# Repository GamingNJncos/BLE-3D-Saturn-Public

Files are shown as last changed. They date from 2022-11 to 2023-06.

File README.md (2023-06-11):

# BLE-3D #
Sega Saturn 3D Controller Bluetooth(BLE) Adapter

# **What does it do?** #
- This is an open source and completely solderless adapter for the Sega Saturn 3D Controller that converts it to a Bluetooth(BLE) HID Gamepad. 
- The end result demonstrates a battery powered and solderless adapter that allows you to use one of the best controllers ever made to date across numerous consoles

### Highlights ###
- **Zero modifications to the factory controller** are neccesary to build, test, or play with this adapter.
- Both Analog, and Digital mode (switch on controller) are fully supported
- Want to revert back to OE? Simply plug the OE cable back in. 
- Latency testing pin on-pcb offers consistent and reproducible testing across code changes and development

### Lowlights ###
- This isn't a "retail ready product", it's a proof of concept
- No case for this has been published yet (bare pcb)
- Power circuit has a couple issues. More details in Caveats section

# **Compatibility** #
 This is an area I'm extremely proud of as of writing the BLE3D is known to work with: 
  - Windows, Linux, and Steamdeck
  - ALL supported [Blueretro](https://github.com/darthcloud/BlueRetro) consoles 
  - That means the 3D is now available on (in no particular order)
        - NeoGeo, Supergun, JAMMA
	- Atari 2600/7800, Master System
	- NES, PCE / TG16, Mega Drive / Genesis, SNES
	- CD-i, 3DO, Jaguar, Saturn, PSX, PC-FX, 
	- JVS (Arcade), Virtual Boy, N64, Dreamcast, PS2, GameCube & Wii
	- I'm sure I'm missing a handful
 
  - Note: the analog pad/triggers support are per console, there is no 'digital emulation' on the analog stick.

# **Background** #
For years I've dreamed of a wireless Sega Saturn 3d Pad, just like the patents intended.

- [US Patent Number US 7488,254 B2](https://patentimages.storage.googleapis.com/a2/97/47/e77a8c63165461/US7488254.pdf)
- [US Patent Number Des. 409, 149](https://patentimages.storage.googleapis.com/3d/96/ad/edd675699738cf/USD409149.pdf)
- [European Patent Number EP 1 332 778 B1](https://patentimages.storage.googleapis.com/ed/ba/17/c22422d5d3cc47/EP1332778B1.pdf)
An inspiration image I have been using in development 

Fast forward many years, I stumbled across some work [Hexfreq](https://twitter.com/hexfreq) was doing with arduino and asked if I could take a look at the code. The rest is history.
From there [Humble Bazooka](https://twitter.com/humblebazooka) and I have spent countless hours to make sure this was a reality. I'd be remissed to leave out [darthcloud](https://twitter.com/darthcloud64) has also been an immense help along the way.

# **PCBs** #
- There are 2 publicly available DIY pcb's for "dev kits". 
- There are various issues or design misses with both pcbs
- They aren't intended for retail use, but you can build one yourself **today**.
- Beveling the controller facing pins is advised 

## **LightWing** ##
 - This is a 'new' revision of the BLE-Saturn-3D that focuses on core functionality. This was optimized as the low cost option for home builders. At current, this is the advised version to use until development can progress farther on the extra features of the HeavyWing 
- PCB: https://oshpark.com/shared_projects/7RqwDWJT 
<BR>  <BR>

## **HeavyWing** ##
- The original PCB. Take the above patents put them in a blender. It adds LCD Support, Motion Controls & Rumble. You can use the LightWing code (better performance) on a Heavywing PCB but will need to change some pin mappings.
- PCB: https://oshpark.com/shared_projects/ki7HbZV4
<BR>  <BR><BR> 

# **BOM** #
## LightWing ###
 - 1x [LightWing PCB](https://oshpark.com/shared_projects/7RqwDWJT)
 - 1x [Adafruit Feather Huzzah32](https://www.adafruit.com/product/3405)
 - 1x Battery
<BR><BR> 
	
## HeavyWing ##
 - 1x [HeavyWing PCB](https://oshpark.com/shared_projects/ki7HbZV4)
 - 1x [Adafruit Feather Huzzah32](https://www.adafruit.com/product/3405) 
 - 1x [HiLetgo GY-521 AKA MPU-6050 Tilt Sensor](http://hiletgo.com/ProductDetail/2157948.html)*  (optional - while it does "work" the kalman filter needs some rework. Must support 3.3v, some are 5v only) 
- 1x OLED 128X64 SSD1306 (optional)
- 1x 3.3v Rumble Motor* (optional - this circuit is not populated on the PCB currently)
- 1x Battery
<BR><BR> 

# **Assembly** #
- Assembly is straightforward, it's just a PCB sandwhich and some solder
- Orientation might be counter intuitive

 ### **LightWing - Assembly** ###
- When you build this lay Segata Face-Down, then set the Feather through the holes with the ESP, USB, and Battery plug facing you
- This provies some additional space for the battery directly under the PCB which would closet match the original patent docs visually
<BR>  <BR>

 ### **LightWing - Installation** ###
- Sega Logo and Button Face top
- Segata faces triggers or back of controller
<BR>   <BR>  <BR>

  ### **HeavyWing - Assembly** ###
   - *Pictures to be uploaded soon*
  
<BR><BR>  
# **Before you compile the code** #
- [PlatformIO installed in VScode](https://docs.platformio.org/en/stable/tutorials/espressif32/arduino_debugging_unit_testing.html), the [platformio.ini](https://github.com/GamingNJncos/BLE-3D-Saturn-Public/blob/main/platformio.ini), and the main.cpp for the Lightwing or the Heavywing
- This has not been tested with Arduino IDE extensively but should compile fine however extremely slow
- If you are mixing and matching LightWing code with the HeavyWing PCB, make sure you change the pinmapping. 
- This is well documented in the code if you jump to "Pinmappings for your PCB version"

## Powering the Device ##
This is direct from the [Adafruit Documentation](https://learn.adafruit.com/adafruit-huzzah32-esp32-feather/power-management)
- There's two ways to power a Feather:
- **You can connect with a USB cable** (just plug into the jack) and the Feather will regulate the 5V USB down to 3.3V.
-  **You can also connect a 4.2/3.7V Lithium Polymer** (LiPo/LiPoly) or Lithium Ion (LiIon) battery to the JST jack. This will let the Feather run on a rechargeable battery.
-  **When the USB power is powered, it will automatically switch over to USB for power**, as well as start charging the battery (if attached). 
- **This happens 'hot-swap' style** so you can always keep the LiPoly connected as a 'backup' power that will only get used when USB power is lost.

<BR><BR> 
# **Caveats and Gotchas** #
 ## A Note on the Huzzah32 revisions ##
  - Check your WROOM version before flashing!
  - There is a NEW revision of the huzzah32 shipping with the Wroom-32-**E** that will have some problems initially when plugged into the controller
  - This is a result of changes to pin IO12 between the D and E modules (and a bootstrap pin) 
  - PCB's were made based on result on the Wroom-32-**D** module and have no issues "out of the box"
  
  - On Wroom-E when the pcb is plugged into the controller at boot similar to boot:0x33 (SPI_FAST_FLASH_BOOT) **invalid header: 0xffffffff**
  - You can burn an efuse to work around this with the espefuse tool. Note this is irreversible, if you are uncomfortable with this try to find another vendor with the 32D in stock   - How to burn the efuse: `espefuse.py --port [com port] --baud 115200 set_flash_voltage 3.3V` confirm the fuse status with `espefuse -p [com port] --baud 115200 summary`. At the bottom it will say **Flash voltage (VDD_SDIO) set to 3.3V by efuse.**
- At the bottom it will say **Flash voltage (VDD_SDIO) set to 3.3V by efuse.**

 ## Battery Warning ##
  - It is *extremely* important that you check the polarity on your battery jack is oriented correctly. There is 0 polarity protection. The charging circuit WILL fry if you plug it in and it's backwards.

 ## Powering Down ##
  - Due to the design of the adafruit feather (esp32) there is no formal power switch. 
  - You must either solder a physical switch on to the battery, **or** unplug it. This is not always easy with the JST connector used so be careful.
 
  ## Charging ##
   - Another unfortunate aspect of the power circuit design on the feather is that the device must be powered on to charge. 
   - There is no "charging mode" so anytime the controller needs to charge it will be broadcasting. 
   - Deep sleep is the best solution for this long term but there are reassons it's not included just yet.

  ## Missing Trigger ##
   - In windows if you go to look at the button inputs in joy.cpl the right trigger is not displayed.  
   - The trigger is there, but you have to use another pad tester to "see it".
  - The picture below *is the expected behavior* and appears to be a problem with joy.cpl in particular.
	<BR> <BR> <BR>

## Various Demos and feature teasers ##
- [Taking Nights for a spin over Bluetooth](https://twitter.com/GamingNJncos/status/1537364206881755136)
- [LCD and customizable Boot Logo](https://twitter.com/GamingNJncos/status/1532819934551724033)
- [Pad Test Demo in X-Men COTA](https://twitter.com/GamingNJncos/status/1537362477817765889)
- [Steamdek Test](https://twitter.com/GamingNJncos/status/1540845741710745602)
- [Early External Unit Testing](https://twitter.com/GamingNJncos/status/1404144038693986307)

## Latency Testing ##
- A significant amount of consideration went into making it easy to test code changes and the impact on latency
- The Lightwing PCB has a dedicated solder pad for consistent testing methodology and code incorporates easy to toggle enable/disable for the pin
- Documentation on the process is available [here](https://github.com/GamingNJncos/BLE-3D-Saturn-Public/tree/main/BlueRetro_Latency_Testing)

## **Note on the Boot Logos (Supported on HeavyWing PCB)** ##
This is documented in the code however if you want to convert images [this tool](https://lcd-image-converter.riuson.com/en/about/) is really useful  
<BR>  <BR>

## Whats with the Names? ##
- Feather add-ons or expansions (hat equivalent for raspberry pi) are called "Wings". 
- Combine that with some Sega nerd-lore and you the [Heavy Wing](https://panzerdragoon.fandom.com/wiki/Heavy_Wing) and [Light Wing](https://panzerdragoon.fandom.com/wiki/Light_Wing)

<BR><BR>

# **Strange notes and pedantic details** #
 ## Protocol Details and Resources ##
 - [A great overview across numerous sega consoles](https://hackaday.io/project/170365-blueretro/log/180790-evolution-of-segas-io-interface-from-sg-1000-to-saturn) by [darthcloud](https://twitter.com/darthcloud64)
 - [Additional protocol details for the Saturn](http://forums.modretro.com/index.php?threads/saturn-controller-protocol-mk80116-mk80100.11328/)

 ## Saturn 3D supported Game list, patent details, and more ##
https://segaretro.org/3D_Control_Pad
 
 ## Polling Oddity or Opportunity? ## 
The [Saturn only polls the 3D protocol at 16ms intervals](https://nfggames.com/forum2/index.php?topic=5055.0) (screen blank). There is however some suggestion in the below post that the Action Replay (this is firmware version specific) can attempt polling faster.  It's worth taking a look at as it may be possible to force games into a faster mode with patching.

Qoute:
"For whatever reason, it's only polling the controller for 14.25ms, with around 310us pauses in between, so it's polling much quicker, but the real issue is after this 14.25ms is up, it then drives the SEL line Hi and goes about it's business for ~2.5ms after that, then back to polling."

## Other demos and informational links ##
- [A DIY internal BlueRetro receiver for Saturn](https://twitter.com/nosIndulgences/status/1573719805496299520)
- [Hexfreq showing off a completely differnt bluetooth saturn solution](https://twitter.com/hexfreq/status/1468282054978818062)

## **Libraries in use** ##
- [ESP32-BLE-Gamepad](https://github.com/lemmingDev/ESP32-BLE-Gamepad)
 - This is subject to change long term as new and improved libraries emerge to support BLE HID gamepads

- [NimBLE-Arduino](https://github.com/h2zero/NimBLE-Arduino)

## **Details on the Feather** ##
- If you want to remix the PCB's or understand more about the feather itself check out the following
- [Feather Pinouts and hardware overview](https://learn.adafruit.com/adafruit-huzzah32-esp32-feather/pinouts)

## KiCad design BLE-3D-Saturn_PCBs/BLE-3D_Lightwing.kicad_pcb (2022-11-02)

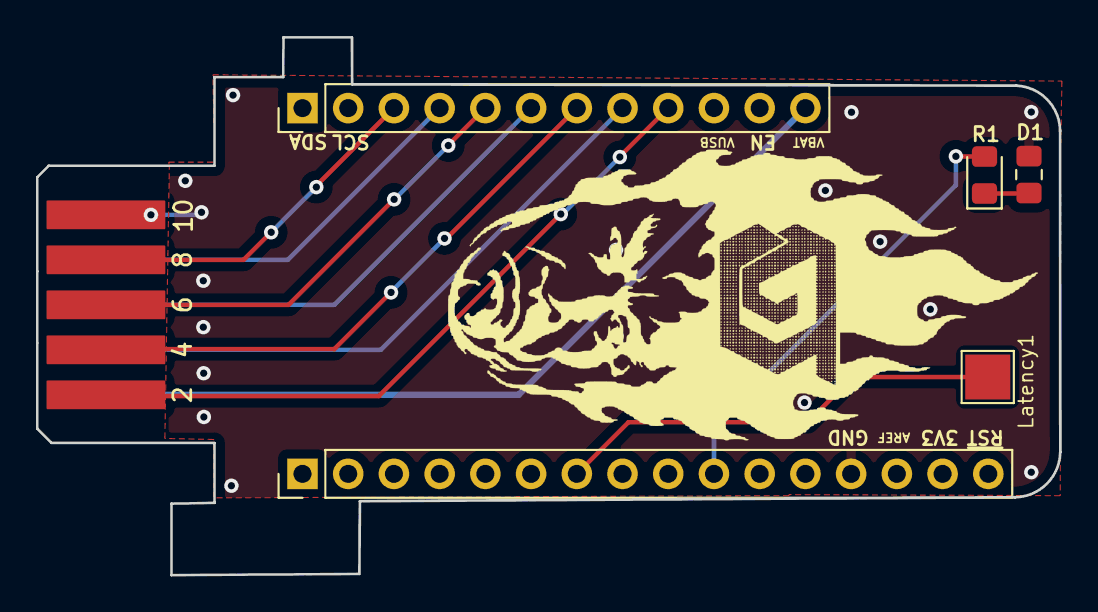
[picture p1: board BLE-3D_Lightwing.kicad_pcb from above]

Board: 2 copper layers, 56.8 x 29.9 mm, 6 parts (1 on the bottom side), 12 nets.

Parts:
D1: LED_Small; R_0805_2012Metric_Pad1.15x1.40mm_HandSolder
J1: feather long; PinHeader_1x16_P2.54mm_Vertical
J2: feather short; PinHeader_1x12_P2.54mm_Vertical
Latency1: Latency; TestPoint_Pad_2.5x2.5mm
R1: R_Small; LED_0805_2012Metric_Pad1.15x1.40mm_HandSolder
U1: Saturn_3D_Pinout; Saturn_Controller_Pinout_2

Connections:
BatLED: J1.10, R1.2
D0: J2.8, U1.3
D1: J2.9, U1.2
D2: J2.3, U1.8
D3: J2.4, U1.7
GND: D1.1, J1.13, U1.9, U1.10
Latency: J1.7, Latency1.1
unnamed: D1.2, R1.1
TH: J2.7, U1.4
TL: J2.5, U1.6
TR: J2.6, U1.5
VBAT: J2.12, U1.1

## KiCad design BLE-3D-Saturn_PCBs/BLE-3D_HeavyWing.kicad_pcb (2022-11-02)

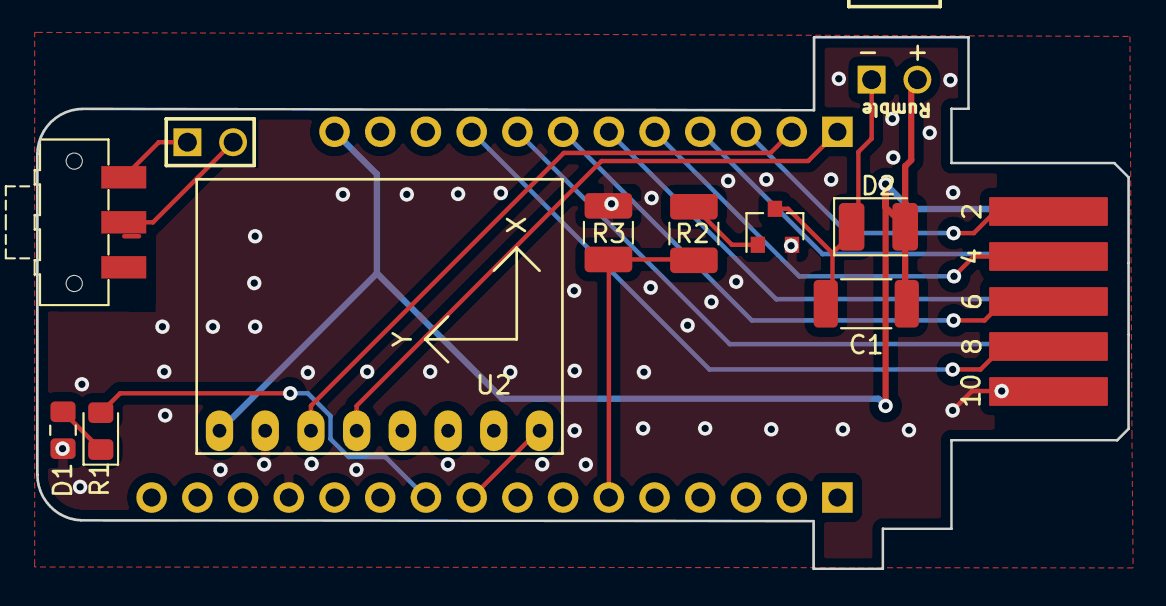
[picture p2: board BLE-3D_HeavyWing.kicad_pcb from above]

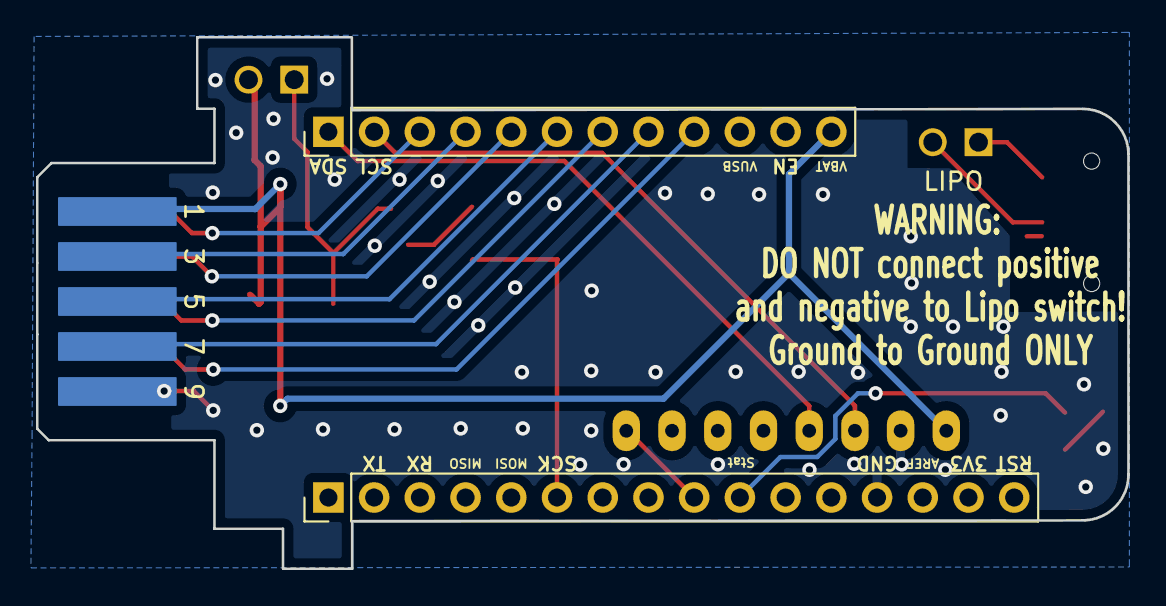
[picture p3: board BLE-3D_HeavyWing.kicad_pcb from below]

Board: 2 copper layers, 60.6 x 29.5 mm, 14 parts (3 on the bottom side), 18 nets.

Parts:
-  +: HEADER-FEMALE-2POS-TH-1x02-JST-PH; HEADER1x2HF
C1: C_Small; C_2010_5025Metric
D1: LED_Small; R_0805_2012Metric_Pad1.15x1.40mm_HandSolder
D2: DIODE; D_1210_3225Metric_Pad1.42x2.65mm_HandSolder
J1: feather long; PinHeader_1x16_P2.54mm_Vertical
J2: feather short; PinHeader_1x12_P2.54mm_Vertical
LIPO: HEADER1X2; HEADER1x2V
Q1: 2N7002; SOT-23
R1: R_Small; LED_0805_2012Metric_Pad1.15x1.40mm_HandSolder
R2, R3: R_Small; R_1210_3225Metric_Pad1.42x2.65mm_HandSolder
SW1: Power; SW_SPDT_CK-JS102011SAQN
U1: Saturn_3D_Pinout; Saturn_Controller_Pinout_2
U2: GY-521

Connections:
BAT_GND: LIPO.1, LIPO.2, SW1.1, SW1.2
BatLED: J1.10, R1.2
D0: J2.4, U1.3
D1: J2.3, U1.2
D2: J2.9, U1.8
D3: J2.8, U1.7
GND: D1.1, J1.13, Q1.2, R3.1, U1.9, U1.10, U2.2
INT: J1.9, U2.8
unnamed: - +.1, C1.2, D2.1, Q1.3
unnamed: D1.2, R1.1
unnamed: Q1.1, R2.2
SCL: J2.2, U2.3
SDA: J2.1, U2.4
TH: J2.5, U1.4
TL: J2.7, U1.6
TR: J2.6, U1.5
VBAT: - +.2, C1.1, D2.2, J2.12, U1.1, U2.1
VibeOut: J1.6, R2.1, R3.2

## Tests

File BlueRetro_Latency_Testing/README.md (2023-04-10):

# This is currently under construction.

# Forward (Rant)
If you are chasing low latency controllers and have never tested your display lag, you are approaching this *completely backwards*. If you are trying to blame controller latency before video as the culprit for how poorly you play games, reconsider. LAG is cumulative from input to output as far as your perception is concerned.

Some of the better projectors for example alone add 30-70ms of lag. It's not uncommon to see with a series of connected devices in path 40-60ms before hitting your "2ms" LCD. Even your LCD is unlikely to perform at advertised speeds outside of VERY specific configurations. Wrong setting, add 18+ms.  That's omitting any upscaler, AV Reciver in the middle, media converters, hdmi switches, etc - each of which may have setting based penalties. 

[RetroRGB](https://www.retrorgb.com/) has done extensive testing and how-to videos on the subject.

# Controller Latency Testing in General
Before we dive into the BLEGamepad/BlueRetro stuff, it's useful to understand how this testing is done in the wild elsewhere. Consistency is important across numerous controllers and setups. The best place to start is with the MiSTER. 

## What you need:
- [x] A controller      - This acts as the "Transmitter" for the keypress

- [x] Arduino Pro Micro - This performs time based calculation for Press->Recieve

- [x] Your reciver      - This is the "Receiving" device
 - For Mister this is via a custom USB Cable
 - It's BlueRetro for Bluetooth Controllers

## Detailed guide on how latency testing is performed on the Mister Platform:
https://www.cathoderayblog.com/lag-test-your-controller-mister-fpga-input-latency-tester/

I strongly advise taking a look over the content above as it will make everything from here much easier to understand. There are also a fair amount of videos floating around about this. Effectively you're using an arduino to "press" a button, and then another pin which will detect how fast that button is recieved on the other end.  The arduino acts as a timer to count the time from when the press is sent to the time it is received and starts the next loop. After *10,000+* itterations, you have a good average input latency.

## The BIG Mister Controller Latency List:
https://rpubs.com/misteraddons/inputlatency

This is a list of controller input latency tests providing a useful comparison across a wide array of controllers as to what is "low latency", whats "Normal" and what is unbearably slow. 

# Latency Testing with [BlueRetro](https://github.com/darthcloud/BlueRetro)
Darthcloud has included in BlueRetro a method to perform testing with the same arduino code that Mister uses. In brief you have to use the correct firmware, set the correct profile, and then use the right GPIO pin to connect to your arduino. You can read some more on this from his dev journal [here](https://hackaday.io/project/170365-blueretro/log/187443-2020-12-26-update-latency-tests-release-v010).

There are some caveats you should be aware of I have spent *many* hours beating my head on a desk over.

- [x] You **MUST** use the "parallel_1P_external.bin" when flashing firmware (Any firmware release version)
 - Console specific or embedded firmwares wont work
 - DO NOT connect your BR reciever to a console (Use **ONLY** external power)
	  
- [x] Before connecting your controller you **MUST** enable the "Latency Test" profile
 - If you fail to do this before connecting the controller you will have to power off the controller and reset blueretro or wait some time
 - Note: This often does not survive power down so confirm each time you need to power the BR adapter up again
	  
- [x] You **MUST** have access to GPIO26 on your BlueRetro testing device.  
 - This could be risky if you only have console BR specific versions that require modification for output pin and the external power (eg. Pre-built N64 Adapter)

- [x] You **MUST** have access to the PCB of your controller to solder on a wire for arduino to "press" your testing button
 - This typically requires modification to your controller PCB, like scraping away the coating to hit a copper trace.
 - This is also why my 3D Controller Lightwing PCBs have a dedicated pin on them to avoid damage.
 - Some controllers (including the Saturn 3D Pad) require a specific voltage (not just ground) so you may need to identify expected resistance

# Latency Testing with [ESP32-BLE-Gamepad](https://github.com/lemmingDev/ESP32-BLE-Gamepad)
ESP32-BLE-Gamepad does not contain any "specific" latency testing function. For testing you simply define a button that works when pulled low and to connect it to the correct controller facing arduino pin. In the code linked this pin should connect to arduino pin 5.
 -  A lesson learned here is to avoid sending a Button ID/Number used elsewhere in code as it will self cancel in your initial loop not being detected **OR** make sure your code contains a check for **all** places that should use the pin and send the update accordingly.

Defining a latency pin code example:
```
      if (digitalRead(latPin) == LOW) { //when arduino pulls this pin low send button press
        bleGamepad.press(BUTTON_1);
      } else {
        bleGamepad.release(BUTTON_1);
      }
```

# Latency test your ESP32-BLE-Gamepad controller with BlueRetro
 I have used "BR" in place of BlueRetro below

###  The Arduino Pro Micro
 1. Flash your Arduino with the [latency test code](https://github.com/misteraddons/inputlatency/blob/main/arduino/MiSTer_USB_Latency_Test_Lemonici/MiSTer_USB_Latency_Test_Lemonici.ino)

 2. Unplug your Arduino

###  The Controller
  3. Upload your ESP32-BLE-Gamepad code to your controller
 
  4. Turn the controller OFF

  5. Solder a wire to your controller pin to use for testing
 
  6. Connect the wire soldered to the controller to Arduino Pin 5
 
###  BlueRetro
  7. [Flash the "parallel_1P_external.bin"](https://github.com/darthcloud/BlueRetro/wiki/BlueRetro-DIY-Build-Instructions) to your BlueRetro reciever and power cycle it
 
  8. Connect GPIO26 (some boards may show as IO26) on BR to Pin 2 of the Arduino
 
  9. Using **Chrome Browser** [connect to BR over bluetooth](https://hackaday.io/project/170365-blueretro/log/180020-web-bluetooth-ble-configuration-interface) and set the mapping profile to "Latency Test" and click save 
 - Note:  There is a "Test" profile in the second box - do not use this.

 - Example of the correct setting:
the right way
     
 ### Start Latency Testing    
 10. Connect to the serial console of your arduino com port (115200 - 8 n 1) 
 - Failure to connect to serial will not allow the code to start running
     
 11. Power on your controller

 12. Check your Serial console to the arduino and confirm it is incrimenting. If so Allow 10k+ itterations to complete to get your latency data.
     Example of the blinking you should see when testing is working correctly.  Note, I you will only see 1 blink (on arduino) vs my install.
     Seizure Warning: the right way

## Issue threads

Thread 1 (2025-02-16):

collect2.exe: error: ld returned 1 exit status

PJSOConnell, 2025-02-16:
When uploading the LightWing main.cpp to the Adafruit Huzzah32, I get the following error.

collect2.exe: error: ld returned 1 exit status
*** [.pio\build\featheresp32\firmware.elf] Error 1

I have attached the full log.

[saturn_ble.txt](https://github.com/user-attachments/files/18816538/saturn_ble.txt)

Closed 2025-02-16.

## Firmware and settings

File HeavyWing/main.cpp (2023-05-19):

#include <Process.h>
#include <stdio.h>
// Add BLE Gamepad
#include <BleGamepad.h>  
// Add OLED
#include <Adafruit_GFX.h>
#include <Adafruit_SSD1306.h>
// Add Adafruit Sensor Libs for Tilt Controls
#include <Adafruit_Sensor.h>
#include <Adafruit_MPU6050.h>

//====================================================
// __________.____     ___________.________ _________   
// \______   \    |    \_   _____/ \_____  \\______  \  
//  |    |  _/    |     |    __)_    _(__  < |    |   \ 
//  |    |   \    |___  |        \  /       \|    `    \
//  |______  /_______ \/_______  / /______  /________  /
//         \/        \/        \/         \/         \/ 
// Greetz and massive thanks to Hexfreq for being a complete bad ass
//
// All reliable controller code foundation is from [at]Hexfreq
// All bugs, poor code choices, and existing PCB designs courtesy of [at]GamingNJncos
// Cheers to [at]Arthrimus for lighting this fire on accident
//
// As I have limited time for mainting this codebase long term attempts have been made to over document code provided
// No Warranty expressed or implied
//====================================================


// OLED Screen Settings
#define SCREEN_WIDTH 128 // OLED display width, in pixels
#define SCREEN_HEIGHT 64 // OLED display height, in pixels
#define OLED_RESET     4 // Reset pin # (or -1 if sharing Arduino reset pin)
#define SCREEN_ADDRESS 0x3C ///< See datasheet for Address; 0x3D for 128x64, 0x3C for 128x32
Adafruit_SSD1306 display(SCREEN_WIDTH, SCREEN_HEIGHT, &Wire, OLED_RESET);

// Establish tasks for ESP32 CPU Core Pinning 
TaskHandle_t Task1;
TaskHandle_t Task2;

// BLEGamePad Settings
// ===================
// Values are Advertised Name, Manufacturer, Battery level 
// Note the battery value is not from a read value here but later blegamepad examples support live update vs 1 time poll
BleGamepad bleGamepad("Reala", "GamingNJncos.HexFreq", 100);
// Purposely set high to permit ease of future additional button combinationsfor to send Meta, home button, etc  
#define numOfButtons 12 
#define numOfHatSwitches 1 //DPAD (not Analog pad)
#define enableX true // Analog Pad
#define enableY true // Analog Pad
#define enableRX true // Triggers
#define enableRY true // Triggers
// Additional button options currently disabled
#define enableZ false
#define enableRZ false
#define enableSlider1 false
#define enableSlider2 false
#define enableRudder false
#define enableThrottle false
#define enableAccelerator false
#define enableBrake false
#define enableSteering false
// End BLEGamePad Settings

// Button State Tracking
// This nets a significant advantage in performance vs not tracking states
// BLE expects ACK per packet so flooding "not pressed" or identical data can add extreme delays
// 
byte previousButtonStates[12];
byte currentButtonStates[12];
//  Button State Array Map
//  ======================
//  MODE,   DPAD,   START, A, B, C, X, Y, Z,     L, R,       Analog PAD
//  [0-1]   [0-8]   [-  Binary Values 0-1 -]     [0-15]     [0-127,0-127]
//  Note Left and Right stick in digital mode will return Binary [0-1] vs [0-15] value in analog mode

// Pinmappings for your PCB version
// It is manditory you select the correct pinout for your board type

// Feather HeavyWing to Controller Pin Mapping
// ===========================================
//PCB: https://oshpark.com/shared_projects/ki7HbZV4
//
//int dataPinD0 = 32; //  Arthrimus Pin 3 = Data D0
//int dataPinD1 = 14; //  Arthrimus Pin 2 = Data D1
//int dataPinD2 = 13; //  Arthrimus Pin 8 = Data D2
//int dataPinD3 = 12; //  Arthrimus Pin 7 = Data D3
//int THPin = 15; // Arthrimus Pin 4 = TH Select
//int TRPin = 33; // Arthrimus Pin 5 = TR Request
//int TLPin = 27;  //    Arthrimus Pin 6 = TL Response
//int batPin = A13; //  Used by BLEGamepad library
//int latPin =  4;   //  Latency testing pin
// End Feather HeavyWing to Controller Pin Mapping


// Feather LightWing to Controller Pin Mapping
// ===========================================
// PCB: https://oshpark.com/shared_projects/7RqwDWJT
//
int dataPinD0 = 12; //  Arthrimus Pin 3 = Data D0
int dataPinD1 = 13; //  Arthrimus Pin 2 = Data D1
int dataPinD2 = 14; //  Arthrimus Pin 8 = Data D2
int dataPinD3 = 32; //  Arthrimus Pin 7 = Data D3
int THPin = 27; // Arthrimus Pin 4 = TH Select
int TRPin = 33; // Arthrimus Pin 5 = TR Request
int TLPin = 15;  //    Arthrimus Pin 6 = TL Response
int batPin = A13; //  Used by BLEGamepad library
int latPin =  4;   //  Latency testing pin
// End Feather HeavyWing to Controller Pin Mapping
// End all Pin Mappings

// BleGamepad Variables
// ====================
int16_t bleAnalogX;  //Analog pad X Axis Output
int16_t bleAnalogY;  //Analog pad Y Axis Output
// DeadZone defined as smallest value to exceed before sending in blegamepad report function
int16_t bleDeadZone = 400; //Set Deadzone via minimum number 
// Analog Triggers
int16_t bleRTrigger; //Right Trigger Analog Output
int16_t bleLTrigger; //Left Trigger Analog Output
// Battery Monitoring variables for BLEGamepad
// Note BLE Gamepad can read battery percent but can not check to transmit value after initial connection
int adcRead = 0;
int batVolt = 0;
// End BleGamepad Variables


// Controller protocol and timing variables
// ========================================
// Data Array for each byte from protocol
boolean dataArrayBit0[8];
boolean dataArrayBit1[8];
boolean dataArrayBit2[8];
boolean dataArrayBit3[8];
boolean dataArrayBit4[8];
boolean dataArrayBit5[8];
boolean dataArrayBit6[8];
boolean dataArrayBit7[8];
// Assorted Protocol Variables
int nibble0Read = 0;  // Confirm 1st Nibble has been read
int byteCounter = 0;  // Current Byte Tracker
int modeCounter = 4;  // Reference for which mode we are currently in Analogue or Digital
int DecodeData = 1;   // Controller Successfully Decoded Data Variable
int curMode = 0;      // This stores the Controller Mode to pass between ESP cores
// Assorted timing oriented variables
unsigned long timeStamp = 0;            // Store time of last update
unsigned long lastTimeStamp = 0;        // Store Last time for comparison
const long interval = 1000;             // Data update check timing
unsigned long currentMillis = millis(); // check timing
// Directional Variables
int upDownValue = 0;
int leftRightValue = 0;
// Trigger Variables
int ltValue = 0;
int rtValue = 0;
// Variables for Data send request and Acknowledgments
int THSEL = 0;
int TRREQ = 0;
int TLACK = 0;
// Sets the number of Bytes required for Digital or Analogue Modes
int AnalogMode = 6;
int DigitalMode = 3;
// End Controller protocol and timing variables


// Gyro and Accelerometer Variables
// =================================
// Gyro is currently disabled in code but my terrible examples should be useful if you wish to use this feature
const int MPU_addr=0x68;               // Define Gyro I2C Address 
int16_t AcX,AcY,AcZ,Tmp,GyX,GyY,GyZ;   // Store all values from MPU
int minVal=265;
int maxVal=402;
double x;
double y;
double z;
// Converted XY Values to BLEGamepad ranges (negative to positive 32K
int xmap;
int ymap;
// Max Values to limit full range of 360 degree motion.
// Will require calibration with your MPU-6050 to identify most comfortable ranges
// Suggest 35-45 Degrees or less relatively comfortable for most use cases
int xmax = 200;
int ymax = 200;
int xmin = 160;
int ymin = 160;
// End Gyro and Accelerometer Variables


//  Boot Logo
// ==========
//Set Image Size for Boot Logo
#define imageWidth 128
#define imageHeight 64
// Image to be displayed
// These can be changed and alternatively set as animations
// Create with "LCD Image Converter" tool or similar
// https://lcd-image-converter.riuson.com/en/about/
const unsigned char myBitmap [] PROGMEM=
{
0x00, 0x00, 0x00, 0x00, 0x00, 0x00, 0x00, 0x00, 0x00, 0x00, 0x00, 0x00, 0x00, 0x00, 0x00, 0x00,
0x00, 0x00, 0x00, 0x00, 0x00, 0x00, 0x00, 0xC0, 0x00, 0x00, 0x00, 0x00, 0x00, 0x00, 0x00, 0x00,
0x00, 0x00, 0x00, 0x00, 0x00, 0x00, 0x03, 0x00, 0x00, 0x00, 0x00, 0x00, 0x00, 0x00, 0x00, 0x00,
0x00, 0x00, 0x00, 0x00, 0x00, 0x00, 0x07, 0x00, 0x00, 0x00, 0x00, 0x00, 0x00, 0x00, 0x00, 0x00,
0x00, 0x00, 0x00, 0x00, 0x00, 0x00, 0x0E, 0x00, 0x00, 0x00, 0x00, 0x00, 0x00, 0x00, 0x00, 0x00,
0x00, 0x00, 0x00, 0x00, 0x00, 0x00, 0x1E, 0x00, 0x00, 0x00, 0x00, 0x00, 0x00, 0x00, 0x00, 0x00,
0x00, 0x00, 0x00, 0x00, 0x00, 0x00, 0x1C, 0x00, 0x00, 0x00, 0x00, 0x00, 0x00, 0x00, 0x00, 0x00,
0x00, 0x00, 0x00, 0x00, 0x00, 0x00, 0x3C, 0x00, 0x00, 0x00, 0x00, 0x00, 0x00, 0x00, 0x00, 0x00,
0x00, 0x00, 0x00, 0x00, 0x00, 0x00, 0x3C, 0x00, 0x00, 0x00, 0x00, 0x00, 0x00, 0x00, 0x00, 0x00,
0x0F, 0xFE, 0x0C, 0x00, 0xF6, 0x0C, 0x3C, 0x00, 0x60, 0x41, 0x80, 0x87, 0xFF, 0xF1, 0x80, 0x1E,
0x1E, 0x3F, 0xFB, 0xE7, 0x9E, 0x0E, 0x3E, 0x00, 0xE7, 0xBE, 0x7F, 0x03, 0xBF, 0x1E, 0xE0, 0x0E,
0x3C, 0x03, 0xE0, 0x7E, 0x03, 0x1E, 0x3E, 0x00, 0xE4, 0x1E, 0x0F, 0x03, 0x1E, 0x1E, 0x78, 0x0C,
0x3E, 0x01, 0xE0, 0x1E, 0x01, 0x1E, 0x3E, 0x01, 0xF0, 0x1E, 0x0F, 0x03, 0x1E, 0x0F, 0x3C, 0x0C,
0x3F, 0x01, 0xE1, 0x3E, 0x00, 0x3F, 0x1F, 0x03, 0xF0, 0x1E, 0x0F, 0x03, 0x1E, 0x0F, 0x3F, 0x0C,
0x1F, 0xC1, 0xE3, 0x3C, 0x00, 0x3D, 0x1F, 0x03, 0xD8, 0x1E, 0x0F, 0x03, 0x1E, 0x1E, 0x3F, 0x8C,
0x0F, 0xF1, 0xFF, 0x3C, 0x00, 0x79, 0x9F, 0x87, 0xD8, 0x1E, 0x0F, 0x03, 0x1E, 0x3E, 0x3F, 0xCC,
0x03, 0xF9, 0xFF, 0x3C, 0x00, 0xF9, 0x8F, 0x87, 0x8C, 0x1E, 0x0F, 0x03, 0x1E, 0xF0, 0x27, 0xEC,
0x00, 0xFD, 0xE3, 0x3C, 0x1F, 0xF0, 0xCF, 0xCF, 0x8C, 0x1E, 0x0F, 0x03, 0x1E, 0x78, 0x31, 0xFC,
0x40, 0x7D, 0xE0, 0x3E, 0x0F, 0xF0, 0xC7, 0xCF, 0x06, 0x1E, 0x0F, 0x03, 0x1E, 0x78, 0x30, 0xFC,
0x60, 0x3D, 0xE0, 0x3E, 0x07, 0xE0, 0x67, 0xDF, 0x06, 0x1E, 0x0F, 0x03, 0x1E, 0x3C, 0x30, 0x7C,
0x30, 0x3D, 0xE0, 0x7E, 0x07, 0xE0, 0x63, 0xFE, 0x03, 0x1E, 0x07, 0x87, 0x1E, 0x3E, 0x30, 0x3C,
0x3E, 0xF9, 0xF3, 0xFF, 0x0F, 0xE0, 0x73, 0xFE, 0x07, 0xBE, 0x07, 0xFE, 0x1F, 0x1F, 0x30, 0x0C,
0x1F, 0xE3, 0xFF, 0xE3, 0xFF, 0xE0, 0xFB, 0xFE, 0x07, 0xFF, 0x01, 0xF8, 0x3F, 0x87, 0xF0, 0x04,
0x00, 0x00, 0x00, 0x00, 0x00, 0x00, 0x03, 0xE0, 0x00, 0x00, 0x00, 0x00, 0x00, 0x00, 0x38, 0x00,
0x00, 0x00, 0x00, 0x00, 0x00, 0x00, 0x03, 0xE0, 0x00, 0x00, 0x00, 0x00, 0x00, 0x00, 0x00, 0x00,
0x00, 0x00, 0x00, 0x00, 0x00, 0x00, 0x03, 0xC0, 0x00, 0x00, 0x00, 0x00, 0x00, 0x00, 0x00, 0x00,
0x00, 0x00, 0x00, 0x00, 0x00, 0x00, 0x03, 0xC0, 0x00, 0x00, 0x00, 0x00, 0x00, 0x00, 0x00, 0x00,
0x00, 0x00, 0x00, 0x00, 0x00, 0x00, 0x07, 0x80, 0x00, 0x00, 0x00, 0x00, 0x00, 0x00, 0x00, 0x00,
0x00, 0x00, 0x00, 0x00, 0x00, 0x00, 0x07, 0x00, 0x00, 0x00, 0x00, 0x00, 0x00, 0x00, 0x00, 0x00,
0x00, 0x00, 0x00, 0x00, 0x00, 0x00, 0x0E, 0x00, 0x00, 0x00, 0x00, 0x00, 0x00, 0x00, 0x00, 0x00,
0x00, 0x00, 0x00, 0x00, 0x00, 0x00, 0x18, 0x00, 0x00, 0x00, 0x00, 0x00, 0x00, 0x00, 0x00, 0x00,
0x00, 0x00, 0x00, 0x00, 0x00, 0x00, 0x00, 0x00, 0x00, 0x00, 0x00, 0x00, 0x00, 0x00, 0x00, 0x00
};
// End Boot Logo


// Boot Logo and Screen Setup
// ==========================
void bootLogo(){
  //Check ESP Core Boot Logo is running on
  //Serial.print("BootLogo Core ");
  //Serial.println(xPortGetCoreID());

   if(!display.begin(SSD1306_SWITCHCAPVCC, SCREEN_ADDRESS)) {
    Serial.println(F("SSD1306 allocation failed"));
    for(;;); // Don't proceed, loop forever
  }
  // Rotate
  display.setRotation(2);
  // Clear the Buffer
  display.clearDisplay(); 
  // Draw Animation
  // Draw Bitmap syntax
  // display.drawBitmap(x position, y position, bitmap data, bitmap width, bitmap height, color)
  display.drawBitmap(0, 32, myBitmap, 128, 32, WHITE); 
  display.display();
  // Set Delay for Boot Animation
  delay(1500);
  // Reset Display
  display.display();
  display.setRotation(2);
  delay(10); 
  // Clear the buffer
  display.clearDisplay();
  delay(2000);
  //End Screen Setup
  }


// Battery Related Checks
// ======================
void getBatStat(){
  // Check ESP Core
  //Serial.print("Battery Status Core ");
  //Serial.println(xPortGetCoreID());

  adcRead = analogRead(batPin);
  batVolt = adcRead;
  // Multiply by 2 to correct reading for Featherwing Huzzah32
  //batVolt = adcRead * 2;

  int BatteryPct;
  int oldBatPct = 0;
  // Map Battery voltage range to a percentage
  BatteryPct = map (batVolt, 1200, 4200, 0, 100);
  // Make sure its populated on initial run
  if (oldBatPct < 1){
    oldBatPct = BatteryPct;
  }
  // Super hack check to omit negative values from OLED Updates
  if (BatteryPct < 0 ){
    BatteryPct = oldBatPct;
  }
  
  // Build and send screen update
  // ============================
  String lcdBat;
  lcdBat = "Battery: " + String(BatteryPct) + "%    ";
  //display.setCursor(0,50);
  //display.print("Battery  ");
  //display.setCursor(0,50);
  //display.print(lcdBat);
  //display.display();
  // End Battery Updates
  }

// OLED Updates
// ============
void oled_Updates(){
if (curMode== 0 ) {
  curMode = 0;
  display.setTextSize(1);                       // Normal 1:1 pixel scale
  display.setTextColor(SSD1306_WHITE, BLACK);   // Draw white text
  display.setCursor(0,1);                       // Start at top-left corner
  display.println(F("Mode: Analog "));
  display.display();
  } else {
  curMode = 1;
  display.setTextSize(1);                       // Normal 1:1 pixel scale
  display.setTextColor(SSD1306_WHITE, BLACK);   // Draw white text
  display.setCursor(0,1);                       // Start at top-left corner
  display.println(F("Mode: Digital "));
  display.display();
    }
  // End OLED Updates
  }
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
//void loop(){

//Get Data from MPU
//Wire.beginTransmission(MPU_addr);
//Wire.write(0x3B);
//Wire.endTransmission(false);
//Wire.requestFrom(MPU_addr,14,true);

//Store MPU Values
//AcX=Wire.read()<<8|Wire.read();
//AcY=Wire.read()<<8|Wire.read();
//AcZ=Wire.read()<<8|Wire.read();

Serial.print("MPU X Y Z");
//Serial.print(a.acceleration.x, 1);
//Serial.print(a.acceleration.y, 1);
//Serial.print(a.acceleration.z, 1);
Serial.print("MPU GYRO");
//Serial.print(g.gyro.x, 1);
//Serial.print(g.gyro.y, 1);
//Serial.print(g.gyro.z, 1);

//Convert stored values from Rads to Degrees
//int xAng = map(AcX,minVal,maxVal,-90,90);
//int yAng = map(AcY,minVal,maxVal,-90,90);
//int zAng = map(AcZ,minVal,maxVal,-90,90);
//x= RAD_TO_DEG * (atan2(-yAng, -zAng)+PI);
//y= RAD_TO_DEG * (atan2(-xAng, -zAng)+PI);
//z= RAD_TO_DEG * (atan2(-yAng, -xAng)+PI);

//Print current angles
//Serial.print("AngleX  ");
//Serial.println(x);
//Serial.print("AngleY  ");
//Serial.println(y);
//display.clearDisplay();
//display.setTextSize(1);             // Normal 1:1 pixel scale
//display.setTextColor(SSD1306_WHITE, BLACK);        // Draw white text
//display.setCursor(0,10);
//display.println("Tilt: On");
//display.setCursor(0,20);             // r
//String derp1 = "   X Axis: " + String(x);
//String derp2 = "   Y Axis: " + String(y);
//display.clearDisplay();
//display.println(derp1);
//display.println(F("X Axis " + String(x)));
//display.setCursor(0,30);
//display.println(derp2);
//display.println(F("y Axis " + String(y)));
//display.display();
//

//Limit Degrees of angle based on comfort prior to converting to BLEGamepad Vals
//Limit X
if (x < 160){
  x=160;
}
if (x > 200){
  x=200;
}
//Limit Y
if (y < 160){
  y=160;
}
if (y > 200){
  y=200;
}

//Define DeadZones 
//Will require calibration based on your install
//
//Create X deadzone
if ((x >= 170) && (x <= 190)){
  x=180;
}
//
//Create Y deadzone
if ((y >= 170) && (y <= 190)){
  y=180;
}

//Map Values to Gamepad Ranges
xmap = map (x, 160, 200, 0, 32767);
ymap = map (y, 160, 200, 0, 32767);
//Print Mapped values
//Serial.print("Xmap BleG: ");
//Serial.println(xmap);
//Serial.print("Ymap BleG: ");
//Serial.println(ymap);

Serial.println("-----------------------------------------");

}

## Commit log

2022-11-01 Initial code release
    Come checkout my bugs
    [main.cpp]
2022-11-02 Add kicad PCB exports for direct Download
    [BLE-3D_HeavyWing.kicad_pcb, BLE-3D_Lightwing.kicad_pcb]
2022-11-02 Add PCBs
    [BLE-3D_HeavyWing.kicad_pcb, BLE-3D_Lightwing.kicad_pcb]
2023-06-11 Update README.md
    Wroom-32-E Notes and Power
